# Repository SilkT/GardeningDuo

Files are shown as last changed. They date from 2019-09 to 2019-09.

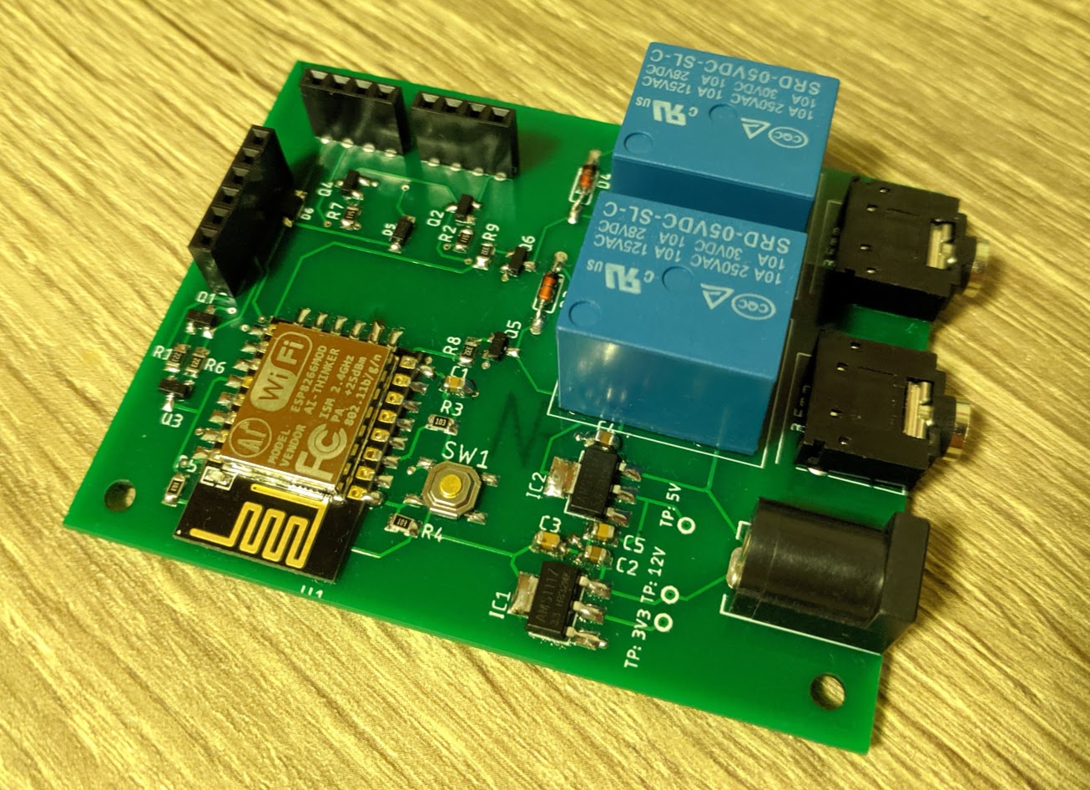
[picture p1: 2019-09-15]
IMG_20190807_213601.jpg

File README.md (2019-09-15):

# GardeningDuo
ESP8266 based automated plants watering
Project is based on ESP8266 Wi-Fi enabled microcontroller and use of two analog moisture sensors. The data is logged from said sensors and compared to values stored in cloud represented by google spreadsheet accesed by connecting to internet. In case of necessity, the relay on board is triggered and the plant is watered using the connected pump. Information from sensors is also logged and stored in a spreadsheet, where is can be displayed as a graph. Hardware part of the project consists of esp12e breakout board, dual moisture sensors, and two relays that control the pumps. For software, Arduino IDE is used because of high availability of  open source code and simplicity of work with esp8266 chips.
Only Hardware part is avalible in this repo at the moment.

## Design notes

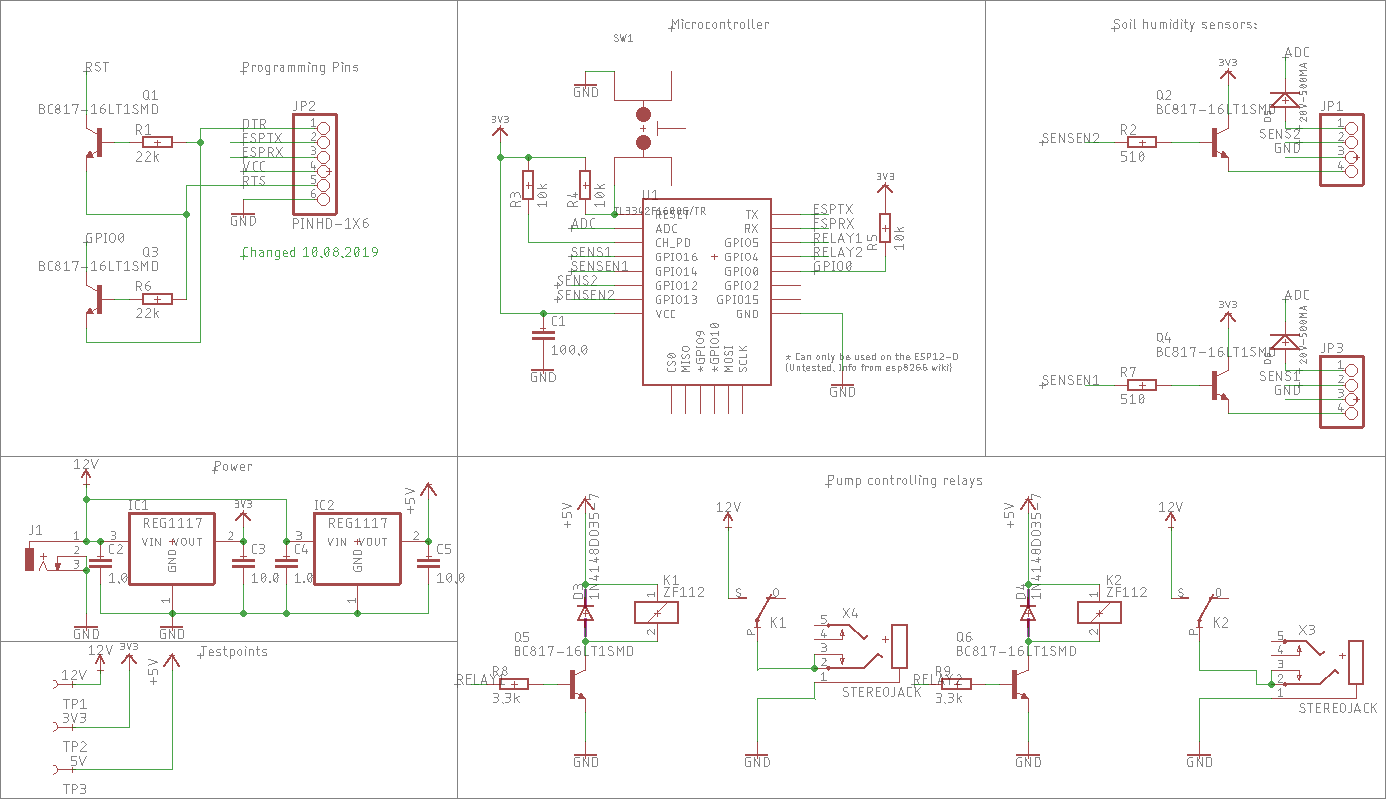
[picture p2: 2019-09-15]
Hardware/eagle_2019-09-15_23-07-17.png

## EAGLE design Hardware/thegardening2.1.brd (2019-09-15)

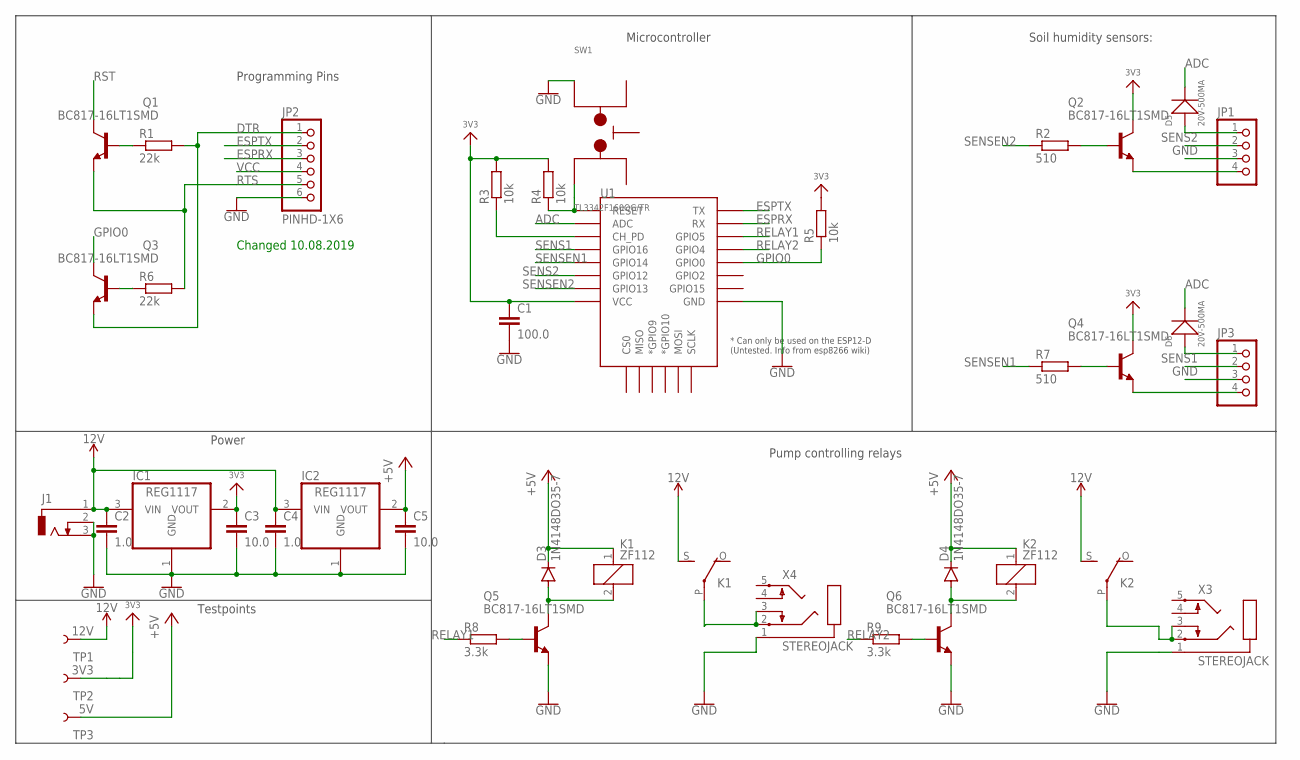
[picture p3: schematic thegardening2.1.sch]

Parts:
C1: 100.0; C0805
C2, C4: 1.0; C0805
C3, C5: 10.0; C0805
D3, D4: 1N4148DO35-7; DO35-7
D5, D6: 20V-500MA; SOD-123
IC1, IC2: REG1117; SOT223
J1: DCJ0303
JP1, JP3: PINHD-1X4; 1X04
JP2: PINHD-1X6; 1X06
K1, K2: ZF112
Q1, Q2, Q3, Q4, Q5, Q6: BC817-16LT1SMD; SOT23-BEC
R1, R6: 22k; R0805
R2, R7: 510; R0805
R3, R4, R5: 10k; R0805
R8, R9: 3.3k; R0805
SW1: TL3342F160QG/TR
TP1: 12V; TP_15TH
TP2: 3V3; TP_15TH
TP3: 5V; TP_15TH
U1: ESP12ESMD; ESP12E-SMD
X3, X4: STEREOJACK; STX3100

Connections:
+5V: C5.1, D3.C, D4.C, IC2.2 (VOUT), K1.1, K2.1, TP3.P$1
ADC: D5.-, D6.-, U1.ADC
DTR: JP2.1, Q3.E, R1.2
ESPRX: JP2.3, U1.RXD0 (RX)
ESPTX: JP2.2, U1.TXD0 (TX)
GND: C1.2, C2.2, C3.2, C4.2, C5.2, IC1.1 (GND), IC2.1 (GND), J1.2, J1.3, JP1.3, JP2.6, JP3.3, Q5.E, Q6.E, SW1.3, U1.GND, X3.1, X4.1
GPIO0: Q3.C, R5.1, U1.GPIO0
unnamed: D3.A, K1.2, Q5.C
unnamed: K1.P, X4.2, X4.3
unnamed: D5.+, JP1.1
unnamed: D4.A, K2.2, Q6.C
unnamed: K2.P, X3.2, X3.3
unnamed: JP3.4, Q4.E
unnamed: JP1.4, Q2.E
unnamed: Q2.B, R2.2
unnamed: Q4.B, R7.2
unnamed: D6.+, JP3.1
unnamed: Q1.B, R1.1
unnamed: Q3.B, R6.1
unnamed: R3.1, U1.CH_PD
unnamed: Q5.B, R8.2
RELAY1: R8.1, U1.GPIO5
RELAY02: Q6.B, R9.2
RELAY2: R9.1, U1.GPIO4
RST: Q1.C, R4.1, SW1.1, U1.RESET
RTS: JP2.5, Q1.E, R6.2
SENS1: JP3.2, U1.GPIO16
SENS2: JP1.2, U1.GPIO12
SENSEN1: R7.1, U1.GPIO14
SENSEN2: R2.1, U1.GPIO13
VCC: C1.1, C3.1, IC1.2 (VOUT), JP2.4, Q2.C, Q4.C, R3.2, R4.2, R5.2, TP2.P$1, U1.VCC
VCC_2: C2.1, C4.1, IC1.3 (VIN), IC2.3 (VIN), J1.1, K1.S, K2.S, TP1.P$1

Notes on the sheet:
Programming Pins
Microcontroller
Soil humidity sensors:
Pump controlling relays
Power
Testpoints
Changed 10.08.2019

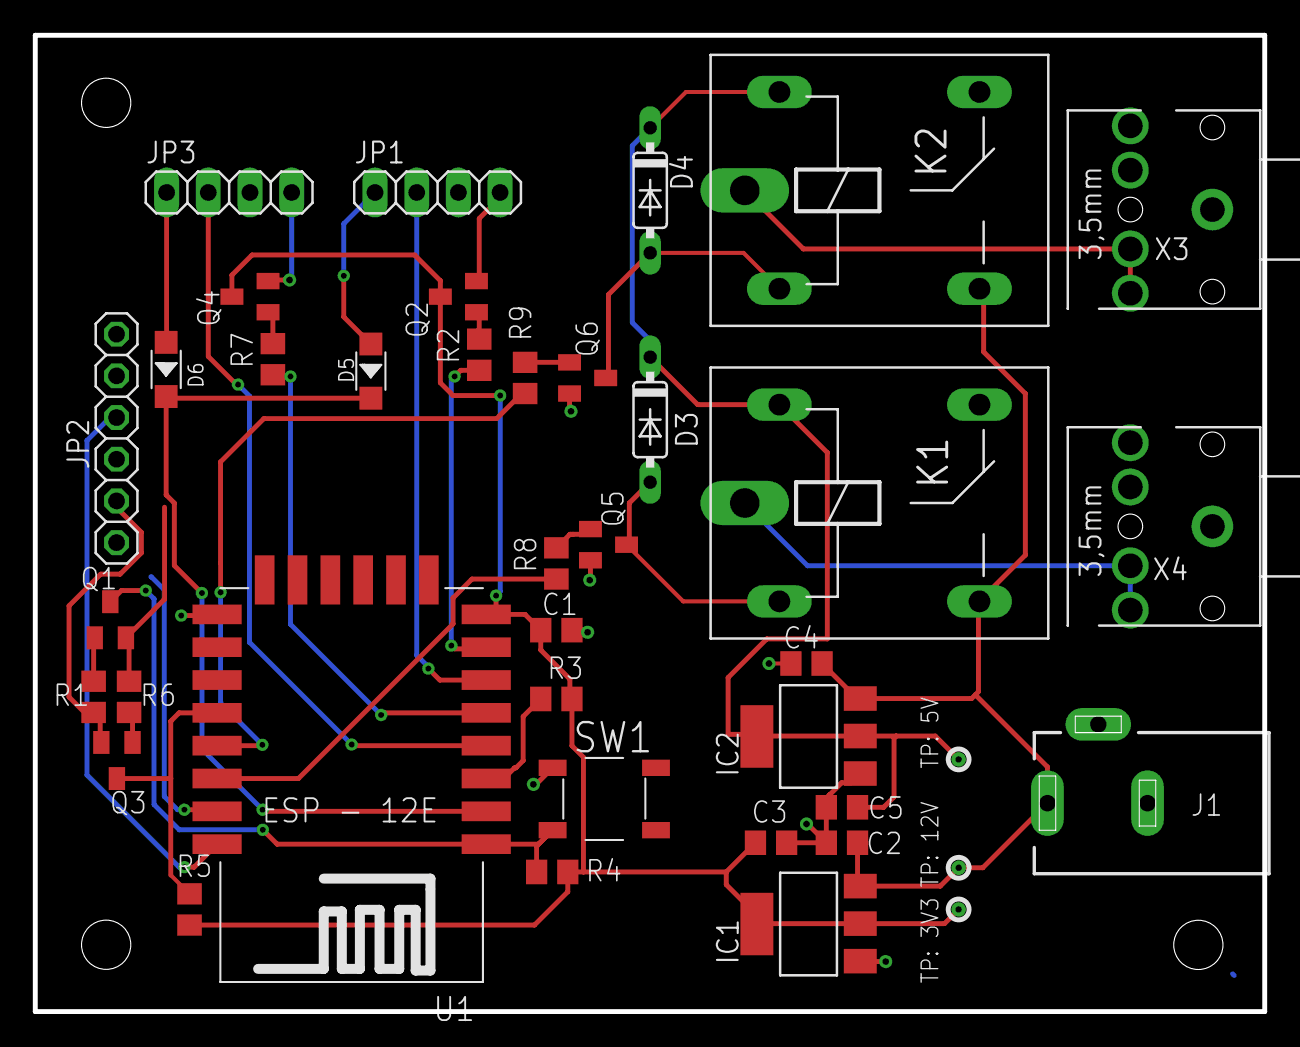
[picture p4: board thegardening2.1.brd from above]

Board: 2 copper layers, 74.9 x 59.5 mm, 39 parts (0 on the bottom side), 32 nets.

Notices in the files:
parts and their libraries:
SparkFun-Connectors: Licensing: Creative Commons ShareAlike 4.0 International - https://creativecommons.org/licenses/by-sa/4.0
